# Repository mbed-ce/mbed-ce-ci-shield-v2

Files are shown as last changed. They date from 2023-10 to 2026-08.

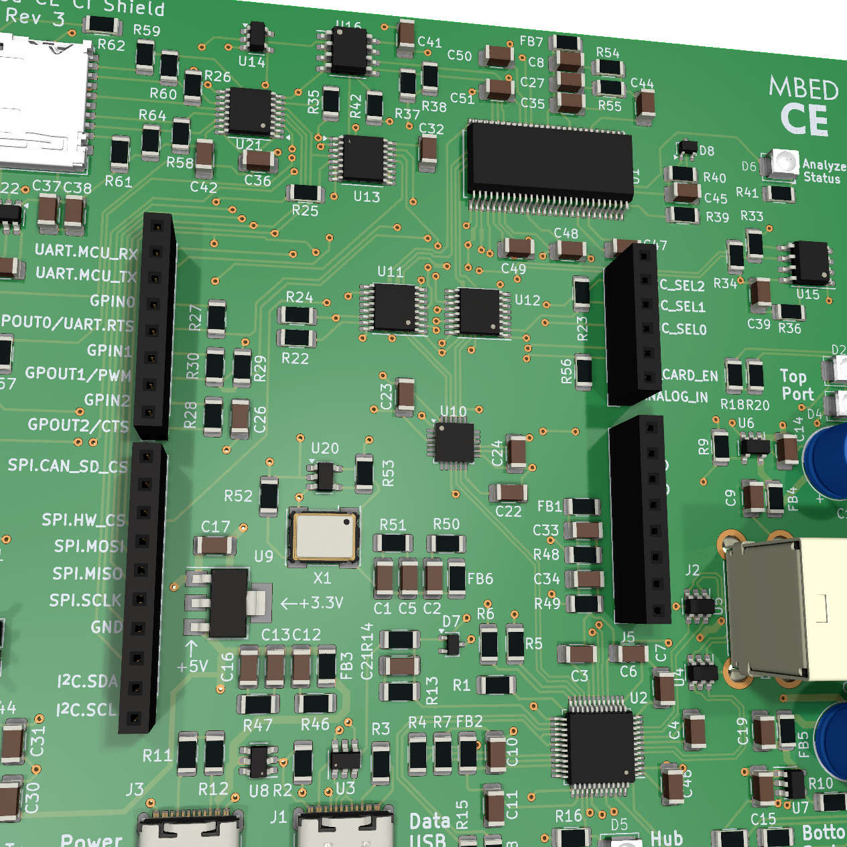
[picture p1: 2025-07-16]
Design Files/Rev3/img/render/mbed-ce-ci-shield-v2-top.png

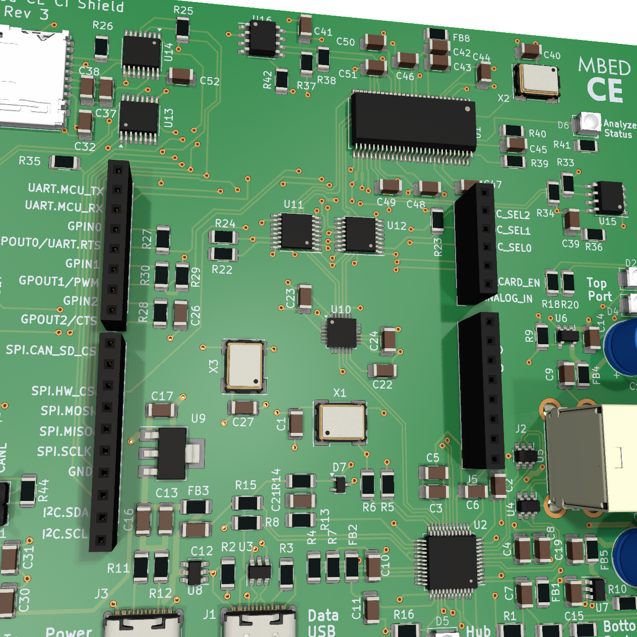
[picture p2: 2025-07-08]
Design Files/Rev3_rc1/img/render/mbed-ce-ci-shield-v2-top.png

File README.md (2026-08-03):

# Mbed CE CI Shield v2
CI Shield Board Photo
This repository contains version 2 of Mbed OS Community Edition's CI Test Shield board.  This PCB is designed to help test the low-level I/O functionality of many different MCUs supported by Mbed OS.

## High Level Functionality
This board contains the following hardware:
- 1x Infineon (Cypress) CY7C65632 4-Port USB 2.0 Hub
  - 2 ports are available externally, 2 ports are connected internally
- 1x Infineon (Cypress) CY7C65211 USB to SPI/I2C/UART adapter
  - This is connected to a number of different data lines via 4-to-1 multiplexer ICs.
- 1x Infineon (Cypress) FX2LP USB Microcontroller
  - This is programmed with Sigrok FX2LAFW firmware to turn it into an inexpensive plug-and-play logic analyzer
- 1x MicroSD card slot
- 1x 24FC64-I/SN 8KiB EEPROM
- 1x PWM to ADC loopback
- 1x Power USB Port (designed to be connected to a power source like a travel charger, data lines not hooked up)
- 1x Data USB Port (designed to be connected to a test runner machine, potentially a single board computer without too much power)

*Note: I swear I'm not sponsored by Infineon or anything, it just so happened that their chips were the best fit for everything I needed on the board.  I even tried to use an FT232H in the first rev of the hardware, but I could not for the life of me get it to work.*

It can test up to 10 different types of IO:
| IO Type | Test Method |
|---|---|
| **USB Device** | The Mbed target's USB Device port can be connected to one of the shield's downstream USB ports |
| **SPI Master** | The Mbed target can interact with the MicroSD card.  The logic analyzer can observe this interaction. |
| **SPI Slave** | The CY7C65211 can initiate SPI transactions which are handled by the MCU.  The logic analyzer can observe this interaction. |
| **I2C Master** | The Mbed target can talk to the EEPROM over I2C.  The logic analyzer can observe this interaction. |
| **I2C Slave** | The CY7C65211 can initiate I2C transactions which are handled by the MCU.  The logic analyzer can observe this interaction. |
| **UART** | The MCU can communicate with the CY7C65211 bidirectionally over UART.  The logic analyzer can observe this interaction. |
| **GPIO** (incl. interrupts) | The shield has 3 sets of "looped back" GPIOs, through which the MCU can send signals to itself.  The logic analyzer can observe this interaction. |
| **PWM** | The MCU outputs a PWM signal via GPIN1.  The logic analyzer measures the frequency and duty cycle. |
| **ADC** (AnalogIn) | The MCU outputs a PWM signal, which is averaged via an RC filter into a voltage.  This voltage is fed into the ADC and the test verifies whether it's read correctly. |
| **DAC** (AnalogOut) | The DAC outputs an analog signal which is fed into an ADC pin.  The test verifies whether the output matches the input. |

## Board Design Files

The complete schematic PDF can be seen here: https://github.com/mbed-ce/mbed-ce-ci-shield-v2/blob/master/Design%20Files/Rev2/docs/mbed-ce-ci-shield-v2-schematic.pdf

## The Logic Analyzer

### Input Mapping

Logic analyzer inputs are muxed by the FUNC_SEL[0..2] pins.

| Analyzer Input | FUNC_SEL = 000 | FUNC_SEL = 001 | FUNC_SEL = 010 | FUNC_SEL = 1xx |
|---|---|---|---|---|
| D0 | UART.MCU_TX | NC | SPI.HW_CS | NC |
| D1 | UART.RTS | I2C.SCL | SPI.MISO | NC |
| D2 | UART.CTS | I2C.SDA | SPI.MOSI | NC |
| D3 | UART.MCU_RX | NC | SPI.SCLK | NC |
| D4 | SPI.SD_CS | SPI.SD_CS | SPI.SD_CS | SPI.SD_CS |
| D5 | GPOUT0 | GPOUT0 | GPOUT0 | GPOUT0 |
| D6 | GPOUT1/PWM | GPOUT1/PWM | GPOUT1/PWM | GPOUT1/PWM |
| D7 | GPOUT2 | GPOUT2 | GPOUT2 | GPOUT2 | 

## Board Bringup and Testing
### Initial Testing
Before powering on a board, check that the resistance across the 5V rail is at least 10kOhms and the resistance across the 3V3 rail is at least 600 ohms.  These rails can be found on the LD1117S33 voltage regulator pins. For ground, use the outside of the double USB-A port (NOT the USB-C ports, their shields are not grounded). If these resistance checks fail, you almost certainly have a short somewhere.

When you first plug in a board, you should see three USB devices enumerate:
- One "Cypress Semiconductor Corp. Unprogrammed CY7C65632/34 hub HX2VL"
- One "Cypress Semiconductor Corp. USB-Serial (Single Channel)"
- One FX2LP in no-EEPROM mode (TODO what is this named in lsusb?)

If these USB devices do not enumerate, double-check the circuitry for the chips that don't enumerate.

Additionally, the current draw of the board should be between ~14mA and ~100mA when no Mbed board is connected.  A USB-C power meter (e.g. [this one](https://www.amazon.com/YOJOCK-Multimeter-Capacity-Voltmeter-Detector/dp/B0B99Z2GJK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)) is highly recommended when testing new boards.

### Flashing Logic Analyzer Firmware

To build and flash the logic analyzer firmware, you will need [Small Device C Compiler](https://sdcc.sourceforge.net/).  On Ubuntu, this can be installed with `sudo apt install sdcc sdcc-libraries`.  You will also need [the mbed-ce fork of fxload](https://github.com/mbed-ce/fxload).  Lastly, you will need access to a Linux command line environment -- WSL or MSYS2 should work if on Windows.

After installing these (and setting up udev rules for fxload, if on Linux), run the following commands from the repo root:

```
$ cd Firmware
$ python3 fx2lafw_update_serial_number.py 001 <replace 001 with the serial number you want to give this board>
$ cd sigrok-firmware-fx2lafw
$ ./autogen.sh
$ mkdir build
$ cd build
$ ../configure
$ make
$ fxload load_eeprom --ihex-path hw/sigrok-fx2-8ch/fx2lafw-sigrok-fx2-8ch.ihx -t FX2LP --control-byte 0xC2
```

Finally, unplug and replug the board from power and data.

Note: The python script run in step 2 works by modifying one of the fx2lafw source files to inject a unique serial number into the firmware, as I wasn't able to find any other way to do this.

### Flashing USB-Serial Adapter Configuration

To configure the USB-serial adapter (the CY7C65211), you will need to use Mbed CE's [cy_serial_bridge](https://github.com/mbed-ce/cy_serial_bridge) library.  This can be installed using `python3 -m pip install cy_serial_bridge`.  Then, we can use the following commands to load a configuration and program the serial number.

Note: If you have any other CI shields connected to the computer, you must unplug them before running these commands.

```
$ cy_serial_cli --pid 0x00fb load Firmware/CY7C65211-Configs/mbed_ce_cy7c65211a_cdc_base_config.bin
$ cy_serial_cli reconfigure --set-serno ShieldSN001 <replace 001 with the serial number you want to give this board>
$ cy_serial_cli change-type I2C # Change to I2C initially so it will not drive any lines on the board
```

## Using the Logic Analyzer
The logic analyzer integrated into this board runs firmware from the Sigrok project, and is designed to be used with the sigrok CLI and the PulseView GUI.  This provides a complete set of open-source tools for capturing and decoding traffic moving across the board.

### Side Note: Sigrok Windows Issues
There is currently no Sigrok/Pulseview release that is compatible with Windows 10 and fx2lafw; neither the nightlies nor the official releases.  I have contributed a [patch](https://github.com/sigrokproject/libsigrok/pull/242) that allows it to work, but to use it, you must install MSYS2 and compile libsigrok, libsigrok-decode, and pulseview from source.

### Using the Logic Analyzer via WSL2 on Windows
If you have Windows 11 and WSL2, you can proxy USB devices to WSL using `usbipd`.  I found that this worked perfectly fine for the FX2 logic analyzer on the board.  First install usbipd using [these instructions](https://github.com/dorssel/usbipd-win/wiki/WSL-support).  Then, follow the linux instructions which follow.

### Using the Logic Analyzer on Linux
First, you need to install the udev rules. Copy the 60-libsigrok.rules and 61-libsigrok-plugdev.rules files from [here](https://github.com/sigrokproject/libsigrok/blob/master/contrib/) into /etc/udev/rules.d.  Then, make sure your user account is in the `plugdev` group.  Finally, run:
```
$ sudo udevadm control --reload-rules
$ sudo udevadm trigger
```

If on WSL2 and the first command gives an error, run
```
$ sudo service udev restart
```
first.

You should now be able to run sigrok without root.  Now, you can run:
```
$ sigrok-cli -d fx2lafw --scan
```
and you should see something like
```
The following devices were found:
fx2lafw:conn=1.4 - sigrok FX2 LA (8ch) with 8 channels: D0 D1 D2 D3 D4 D5 D6 D7
```
This means your logic analyzer is working!

## Building the Design with KiBot

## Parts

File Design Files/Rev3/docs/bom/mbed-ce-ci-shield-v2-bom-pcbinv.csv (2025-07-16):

References | Description | Part | Value | Supplier | SKU | Footprint | LibRef | Qty
C1 C3 C4 C6 C7 C10 C11 C16 C23 C24 C32 C35 C38 C39 C41 C44 C45 C46 C47 C48 C49 C50 C51 | Unpolarized capacitor, small symbol | C_Small | 100nF | Digi-Key |  | C_1206_3216Metric | GRM319R72A104KA01D | 23
C14 C15 C22 C25 C26 C28 C29 C30 C31 C36 C40 C42 | Unpolarized capacitor, small symbol | C_Small | 1u | Digi-Key |  | C_1206_3216Metric | CL31B105KBHNNNE | 12
C2 C5 C8 C9 C12 C13 C19 C21 C27 C33 C34 | Unpolarized capacitor, small symbol | C_Small | 2.2uF | Digi-Key | 1276-1291-1-ND | C_1206_3216Metric | CL31B225KBHNNNE | 11
C17 C37 C43 | Unpolarized capacitor, small symbol | C_Small | 10u | Digi-Key |  | C_1206_3216Metric | CL31B106KLHNNNE | 3
C18 C20 | Polarized capacitor, US symbol | C_Polarized_US | 100u | Digi-Key | 493-6630-1-ND | CP_Radial_D8.0mm_P3.50mm | RL81V101MDN1KX | 2
D1 D2 | Green LED 100mcd 20mA Vf=2.1V | AA3528CGSK | AA3528CGSK | Digi-Key | 754-1528-1-ND | AA3528 |  | 2
D5 D6 | Red LED 100mcd 20mA Vf=1.95V | AA3528SURSK | AA3528SURSK | Digi-Key | 754-1537-1-ND | AA3528 |  | 2
D3 D4 | Yellow LED 200mcd 20mA Vf=2V | AA3528SYSK | AA3528SYSK | Digi-Key | 754-1539-1-ND | AA3528 |  | 2
D7 D8 | Schottky barrier diode, SOT-323 | BAT54W | BAT54W | Digi-Key | 4878-BAT54WCT-ND | SOT-323_SC-70 |  | 2
FB1 FB2 FB3 FB4 FB5 FB6 FB7 | Ferrite bead, small symbol | FerriteBead_Small | 300@100MHz | Digi-Key | 732-4654-1-ND | R_1206_3216Metric | 742792121 | 7
J7 | Generic connector, single row, 01x10, script generated (kicad-library-utils/schlib/autogen/connector/) | Conn_01x10 | 1x10 | Digi-Key | SSW-110-03-T-S-ND | PinSocket_1x10_P2.54mm_Vertical | HEADER_10x1_LONG_TAIL | 1
J9 J10 J11 | Generic connector, single row, 01x02, script generated | Conn_01x02_Pin | 1x2 | Digi-Key | 732-5315-ND | PinHeader_1x02_P2.54mm_Vertical | HEADER_2x1 | 3
J6 | Generic connector, single row, 01x06, script generated (kicad-library-utils/schlib/autogen/connector/) | Conn_01x06 | 1x6 | Digi-Key | SAM8865-ND | PinSocket_1x06_P2.54mm_Vertical | HEADER_6x1_LONG_TAIL | 1
J4 J5 | Generic connector, single row, 01x08, script generated (kicad-library-utils/schlib/autogen/connector/) | Conn_01x08 | 1x8 | Digi-Key | SAM8866-ND | PinSocket_1x08_P2.54mm_Vertical | HEADER_8x1_LONG_TAIL | 2
J8 | Micro SD Card Socket with card detection pins | Micro_SD_Card_Det_Hirose_DM3AT | DM3AT | Digi-Key | HR1964CT-ND | microSD_HC_Hirose_DM3AT-SF-PEJM5 |  | 1
J2 | USB Type A connector, stacked | USB_A_Stacked | UJ2-ADH-3-TH | Digi-Key | 102-5876-ND | USB_A_CUI_UJ2-ADH-TH_Horizontal_Stacked |  | 1
J1 J3 | USB 2.0-only 16P Type-C Receptacle connector | USB_C_Receptacle_USB2.0_16P | USB4105-GF-A | Digi-Key | 2073-USB4105-GF-ACT-ND | USB_C_Receptacle_GCT_USB4105-xx-A_16P_TopMnt_Horizontal-ExtraHoleClearance |  | 2
M1 M2 | 0.1" Jumper / Shunt | Jumper | QPC02SXGN-RC | Digi-Key | S9337-ND |  |  | 2
R46 R47 R48 R49 R50 R51 R54 R55 | Resistor, US symbol | R_US | 1 | Digi-Key | P1.0RCT-ND | R_1206_3216Metric | ERJ-8RQF1R0V | 8
R52 R53 | Resistor, US symbol | R_US | 33 | Digi-Key | 541-CRCW120633R0FKEACCT-ND | R_1206_3216Metric | CRCW120633R0FKEAC | 2
R32 R44 | Resistor, US symbol | R_US | 120 | Digi-Key | P120FCT-ND | R_1206_3216Metric | ERJ-8ENF1200V | 2
R17 R18 | Resistor, US symbol | R_US | 270 | Digi-Key | P270FCT-ND | R_1206_3216Metric | ERJ-8ENF2700V | 2
R19 R20 R21 | Resistor, US symbol | R_US | 300 | Digi-Key | P300FCT-ND | R_1206_3216Metric | P300FCT-ND | 3
R1 | Resistor, US symbol | R_US | 649 | Digi-Key | 311-649FRCT-ND | R_1206_3216Metric | RC1206FR-07649RL | 1
R41 | Resistor, US symbol | R_US | 820 | Digi-Key | 311-820FRCT-ND | R_1206_3216Metric | RC1206FR-07820RL | 1
R27 R28 R30 R62 | Resistor, US symbol | R_US | 1k | Digi-Key | P1.00KFCT-ND | R_1206_3216Metric | ERJ-8ENF1001V | 4
R33 R34 | Resistor, US symbol | R_US | 1.1k | Digi-Key | 311-1.10KFRCT-ND | R_1206_3216Metric | RC1206FR-071K1L | 2
R29 | Resistor, US symbol | R_US | 1.5k | Digi-Key | 311-1.50KFRCT-ND | R_1206_3216Metric | RC1206FR-071K5L | 1
R37 R38 | Resistor, US symbol | R_US | 2.2k | Digi-Key | 311-2.20KFRCT-ND | R_1206_3216Metric | RC1206FR-072K2L | 2
R14 R25 | Resistor, US symbol | R_US | 4.7k | Digi-Key | P4.70KFCT-ND | R_1206_3216Metric | ERJ-8ENF4701V | 2
R2 R3 R11 R12 | Resistor, US symbol | R_US | 5.1k | Digi-Key | 311-5.10KFRCT-ND | R_1206_3216Metric | RC1206FR-075K1L | 4
R13 | Resistor, US symbol | R_US | 9.1k | Digi-Key | P9.10KFCT-ND | R_1206_3216Metric | ERJ-8ENF9101V | 1
R15 R22 R23 R24 R26 R31 R35 R36 R39 R42 R43 R45 R56 R57 R58 R59 R60 R61 R63 R64 | Resistor, US symbol | R_US | 10k | Digi-Key | P10.0KFCT-ND | R_1206_3216Metric | ERJ-8ENF1002V | 20
R4 R5 R6 R7 R8 R9 R10 R16 R40 | Resistor, US symbol | R_US | 100k | Digi-Key | P100KFCT-ND | R_1206_3216Metric | ERJ-8ENF1003V | 9
U15 U16 | I2C Serial EEPROM, 2Kb, DIP-8/SOIC-8/TSSOP-8/DFN-8 | 24LC02 | 24FC64-I/SN | Digi-Key | 24FC64T-I/SNCT-ND | SOIC-8_3.9x4.9mm_P1.27mm |  | 2
U14 | Single NOT Gate, Low-Voltage CMOS | 74AHC1G04 | 74AHC1G04 | Digi-Key | 296-1089-1-ND | SOT-23-5 | SN74AHC1G04DBVR | 1
U20 | Single D Flip-Flop, Inverted Output, Low-Voltage CMOS | 74LVC1G80 | 74LVC1G80 | Digi-Key | 296-9851-1-ND | SOT-23-5 | SN74LVC1G80DBVR | 1
U13 | Triple SPDT CMOS Analog Switch, 2.5Ohm Ron, TSSOP-16 | ADG733BRU | ADG733BRU | Digi-Key | ADG733BRUZ-REEL7CT-ND | TSSOP-16_4.4x5mm_P0.65mm |  | 1
U22 | Load Switch w/ Discharge Resistor | AP22913W6-7 | AP22913W6-7 | Digi-Key | AP22913W6-7DICT-ND | SOT-23-6 |  | 1
U6 U7 | Current Limit IC 0.5-1.0A, SOT-23-5 | BD2221G-LBTR | BD2221G-LBTR | Digi-Key | BD2221G-LBTRCT-ND | SOT-23-5 |  | 2
U10 | Full Speed USB to Serial (UART/SPI/I2C) Bridge, 3MHz Max Speed, With GPIOs, 24-QFN | CY7C65211A | CY7C65211A | Digi-Key | 448-CY7C65211A-24LTXI-ND | QFN-24-1EP_4x4mm_P0.5mm_EP2.65x2.65mm-LengthenedPads |  | 1
U2 | 4 Port USB Hub Controller USB 2.0 48-TQFP | CY7C65632-48AXCT | CY7C65632-48AXCT | Digi-Key | 448-CY7C65632-48AXCT-ND | LQFP-48_7x7mm_P0.5mm |  | 1
U1 | CYPRESS FX2LP USB Microcontroller, 48MHz 8051, 16KB RAM, USB 2.0, I2C, SSOP-56 | CY7C68013A-56PVX | CY7C68013A-56PVX | Digi-Key | 448-CY7C68013A-56PVXCT-ND | SSOP-56_7.5x18.5mm_P0.635mm |  | 1
U9 | 800mA Fixed Low Drop Positive Voltage Regulator, Fixed Output 3.3V, SOT-223 | LD1117S33TR_SOT223 | LD1117S33TR | Digi-Key | 497-1242-1-ND | SOT-223-3_TabPin2 |  | 1
U17 | Stand-Alone CAN Controller with SPI Interface, TSSOP-20 | MCP2515-xST | MCP2515-xST | Digi-Key | MCP2515T-I/STCT-ND | TSSOP-20_4.4x6.5mm_P0.65mm |  | 1
U21 | 4 Channel Bidirectional Level Shifter with Selectable Direction, TSSOP-16 | SN74AXC4T774 | SN74AXC4T774 | Digi-Key | 296-SN74AXC4T774PWRCT-ND | TSSOP-16_4.4x5mm_P0.65mm |  | 1
U11 U12 | CMOS DPQT analog multiplexer/demultiplexer, TSSOP-16 | SN74CB3Q3253PWR | SN74CB3Q3253PWR | Digi-Key | 296-19135-1-ND | TSSOP-16_4.4x5mm_P0.65mm |  | 2
U18 U19 | High-Speed CAN Transceiver, separate VIO, silent mode, SOIC-8 | TJA1051T-3 | TJA1051T-3 | Digi-Key | 568-8684-1-ND | SOIC-8_3.9x4.9mm_P1.27mm |  | 2
U3 U4 U5 U8 | Very low capacitance ESD protection diode, 2 data-line, SOT-23-6 | USBLC6-2SC6 | USBLC6-2SC6 | Digi-Key | 497-5235-1-ND | SOT-23-6 |  | 4
X1 | 3.3V HCMOS SMD Crystal Clock Oscillator, Abracon | ASV-xxxMHz | 24.000MHz | Digi-Key | 535-9317-1-ND | Oscillator_SMD_Abracon_ASV-4Pin_7.0x5.1mm | ASV-24.000MHZ-EJ-T | 1

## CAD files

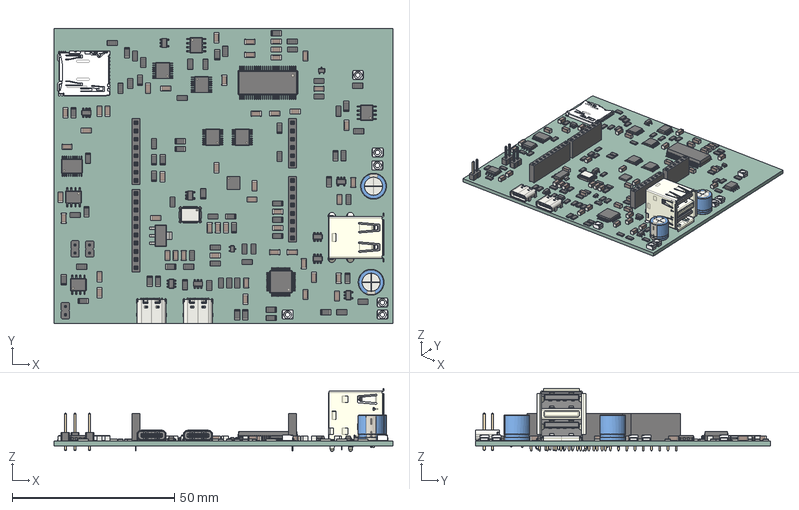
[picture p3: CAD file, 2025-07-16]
Design Files/Rev3/cad/mbed-ce-ci-shield-v2.step
104.5 x 91.0 x 19.4 mm
C_1206_3216Metric x 49
SSOP-56_7.5x18.5mm_P0.635mm
R_1206_3216Metric x 71
TSSOP-16_4.4x5mm_P0.65mm x 4
PinSocket_1x08_P2.54mm_Vertical x 2
CP_Radial_D80mm_P350mm x 2
SOT-23-6 x 5
SOIC-8_3.9x4.9mm_P1.27mm x 4
PinSocket_1x10_P2.54mm_Vertical
SOT-323_SC-70 x 2
USB_C_Receptacle_16P_TopMnt_Horizontal_GCT_USB4105-xx-A x 2
SOT-23-5 x 4
Oscillator_SMD_Abracon_ASV-4Pin_7.0x5.1mm
LQFP-48_7x7mm_P0.5mm
PinSocket_1x06_P2.54mm_Vertical
PinHeader_1x02_P254mm_Vertical x 3
QFN-24-1EP_4x4mm_Pitch0.5mm
DM3AT-SF-PEJM5
TSSOP-20_4.4x6.5mm_P0.65mm
SOT-223
CUI_DEVICES_UJ2-ADH-3-TH
kibot_rdlwfuhl_PCB

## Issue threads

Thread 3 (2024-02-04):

Build and debug first Rev 2 board

multiplemonomials, 2024-02-04:

multiplemonomials, 2024-04-30:
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

multiplemonomials, 2024-05-05:
Notes on things to fix in the PCB:
- Voltage divider which produces reset for CY7C65211 is sized incorrectly, not producing 3.3V.
- SD card is producing some valid data but is not actually coming up.  Need to debug.
- Should add zener diode to make sure that CY7C65211 reset is not high when VDD is 0V, so that the data usb only being plugged in doesn't break stuff.  Also is it a risk of triggering the ESD diode?
- SPI loopback resistor appears to be too high value.  Can't reliably do SPI loopback at 1MHz on LPC1768.  Need to look with a scope, and maybe switch out for like a 2.2k

multiplemonomials, 2024-07-07:
- SD card driver requires a pullup on MISO for correct operation.
- Should set it so that the SPI loopback is only active when the SD card is powered off

multiplemonomials, 2024-08-04:
- On the Arduino Uno R4, pin A0 is the DAC pin.  May wish to move the pinmappings around so that pin A0 is free for DAC purposes.

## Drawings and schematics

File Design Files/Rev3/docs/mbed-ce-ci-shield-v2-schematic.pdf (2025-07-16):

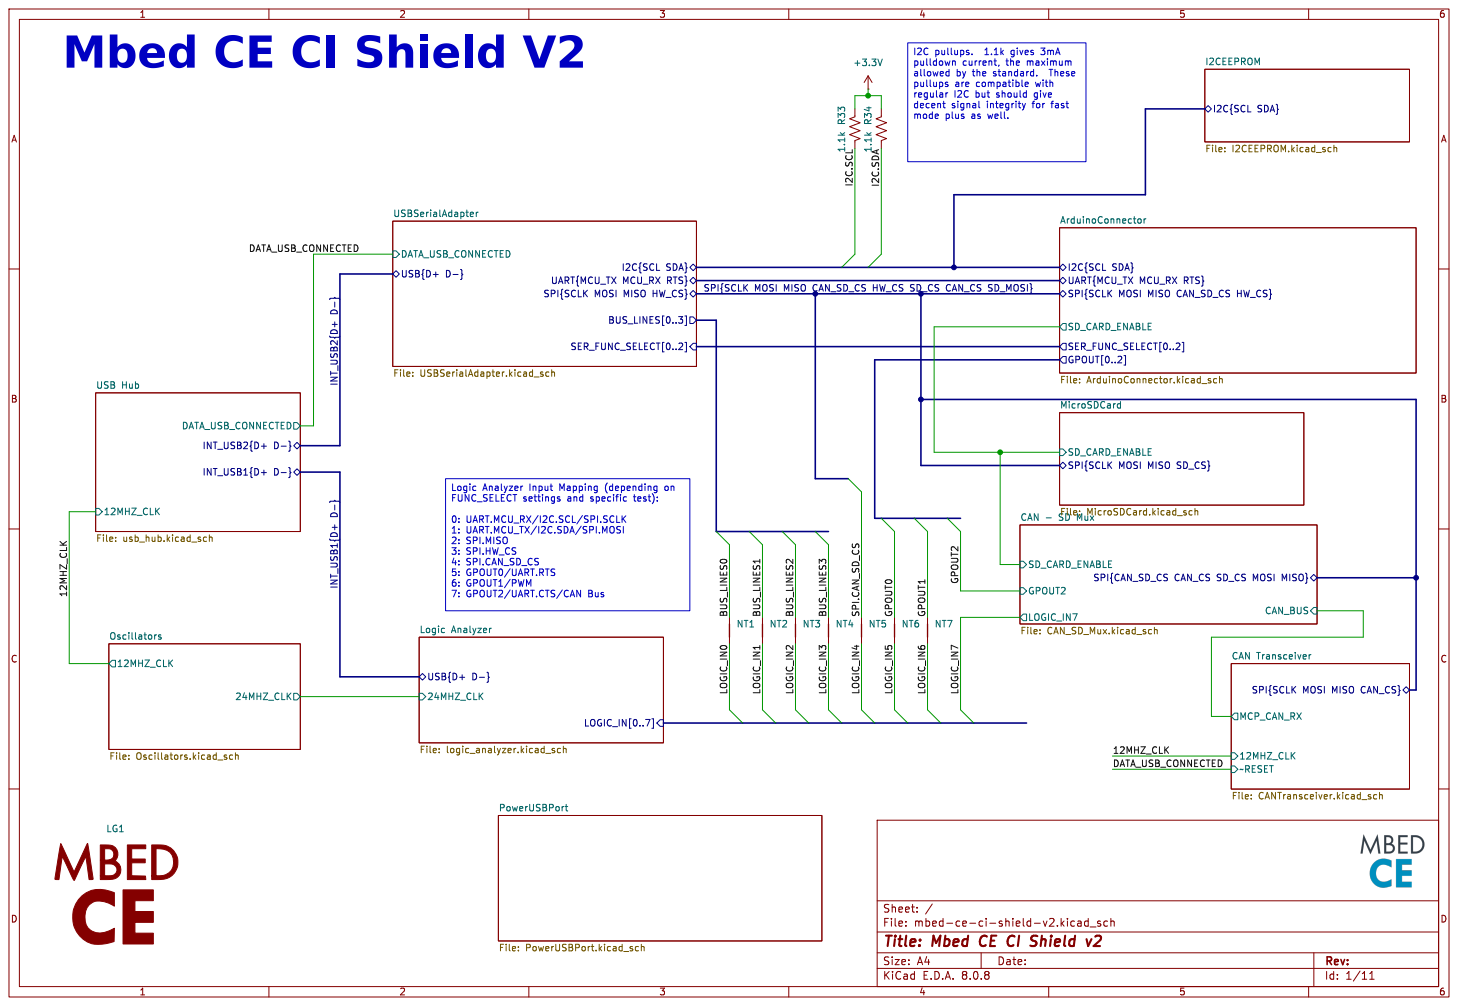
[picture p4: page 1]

USBSerialAdapter File: USBSerialAdapter.kicad_sch PowerUSBPort File: PowerUSBPort.kicad_sch

regular I2C but should give

UART{MCU_TX MCU_RX RTS}
SPI{SCLK MOSI MISO HW_CS}

SPI{SCLK MOSI MISO CAN_SD_CS HW_CS SD_CS CAN_CS SD_MOSI} LOGIC_IN4

SPI{SCLK MOSI MISO CAN_SD_CS HW_CS}

1: UART.MCU_TX/I2C.SDA/SPI.MOSI 2: SPI.MISO

12MHZ_CLK CAN Transceiver File: CANTransceiver.kicad_sch

File: mbed-ce-ci-shield-v2.kicad_sch Sheet: / 12MHZ_CLK

Id: 1/11 Title: Mbed CE CI Shield v2

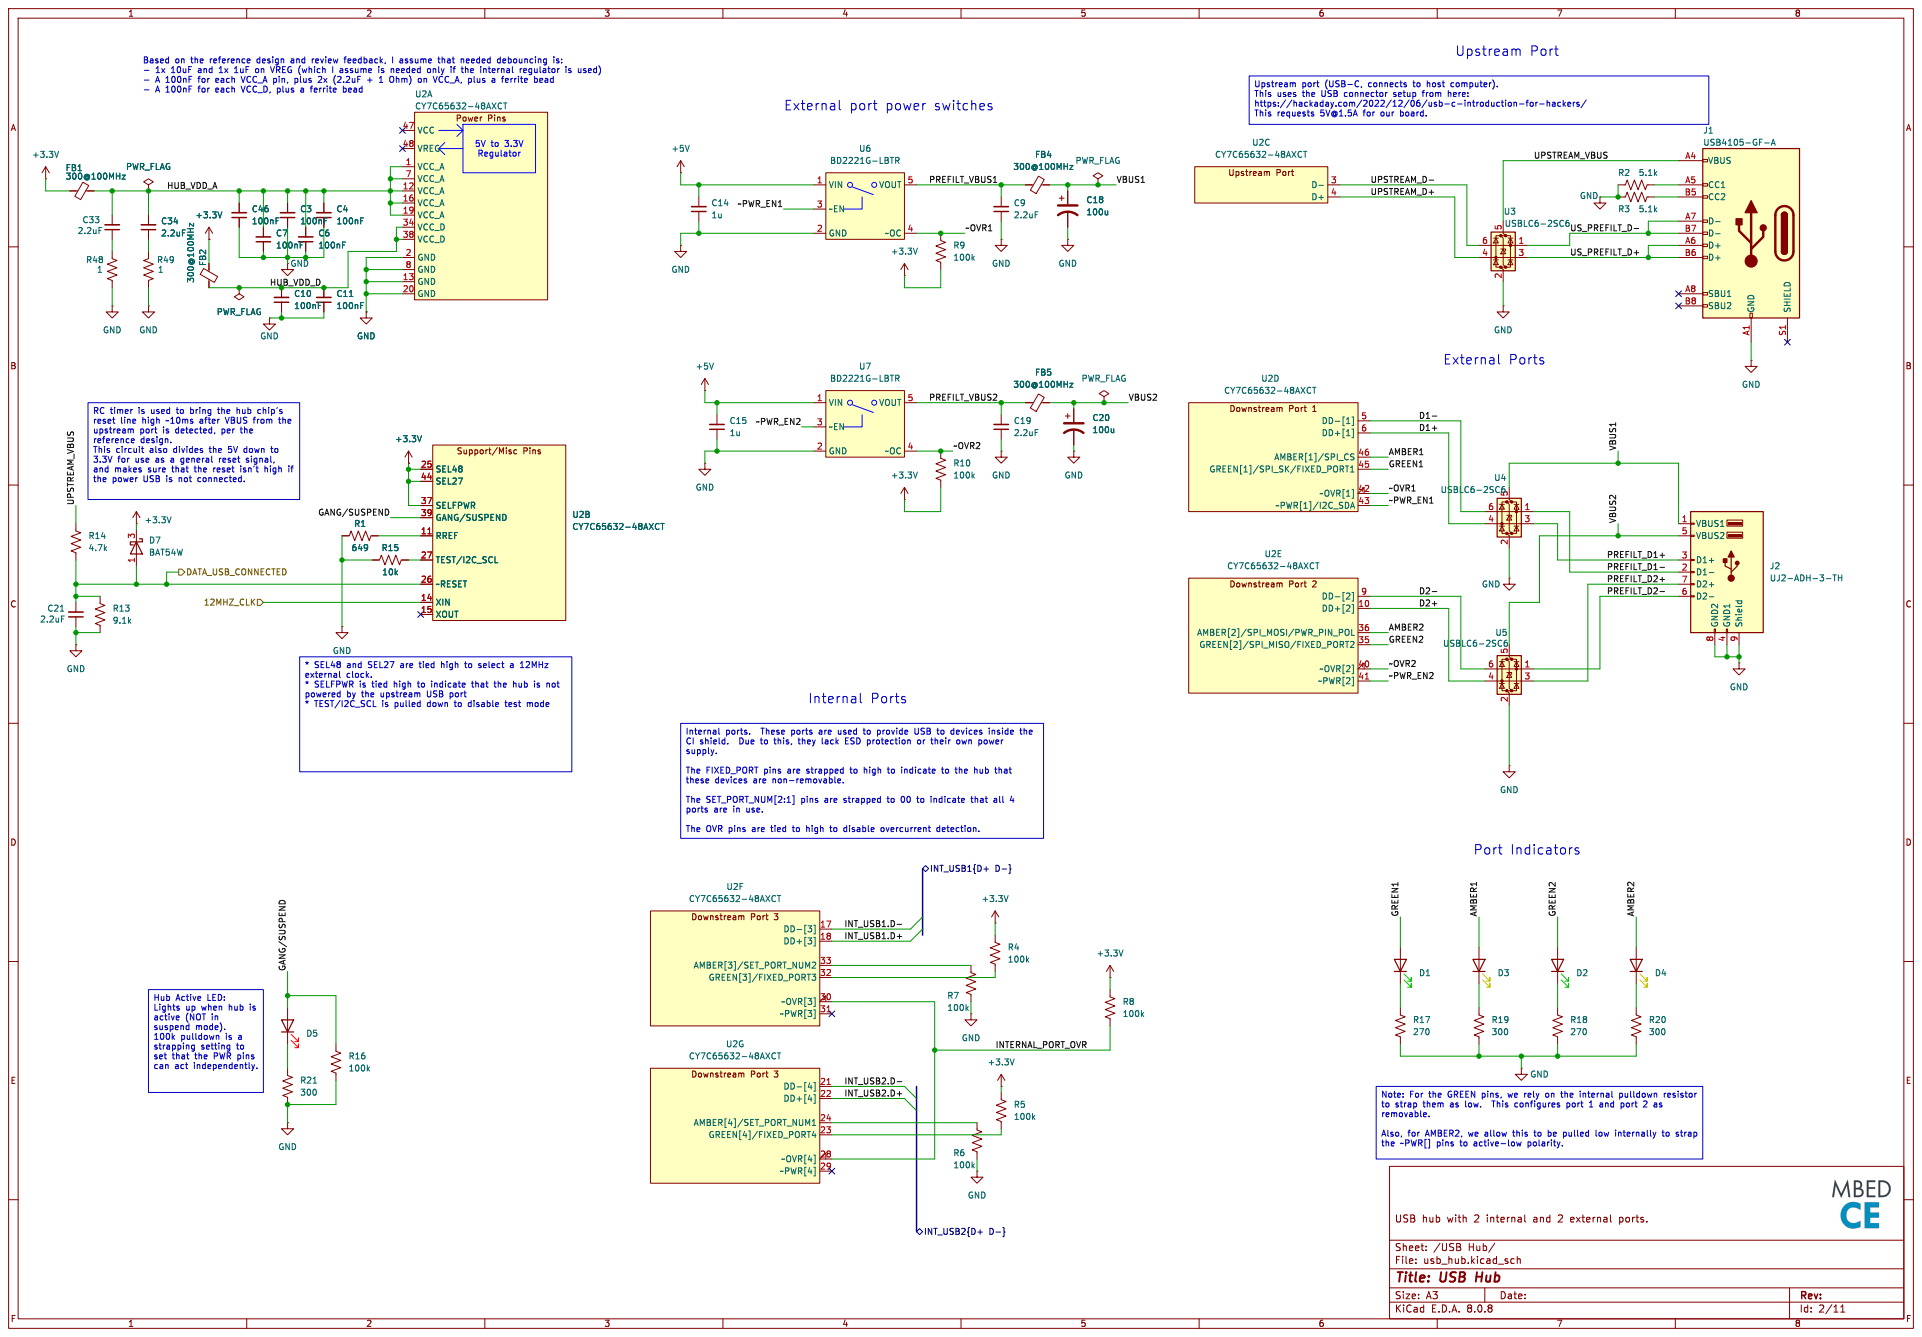
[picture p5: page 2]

- A 100nF for each VCC_A pin, plus 2x (2.2uF + 1 Ohm) on VCC_A, plus a ferrite bead

Regulator Power Pins VCC_A 1 VCC_A 12 GND 13 VCC_A 16 VCC_A 19 GND 2 GND 20 VCC_D 34 VCC_D 38 VCC 47 VREG 48 VCC_A 7 GND 8 U2A CY7C65632-48AXCT

External port power switches

reset line high ~10ms after VBUS from the
3.3V for use as a general reset signal, and makes sure that the reset isn't high if

Hub Active LED: Lights up when hub is active (NOT in

set that the PWR pins

Id: 2/11 Title: USB Hub

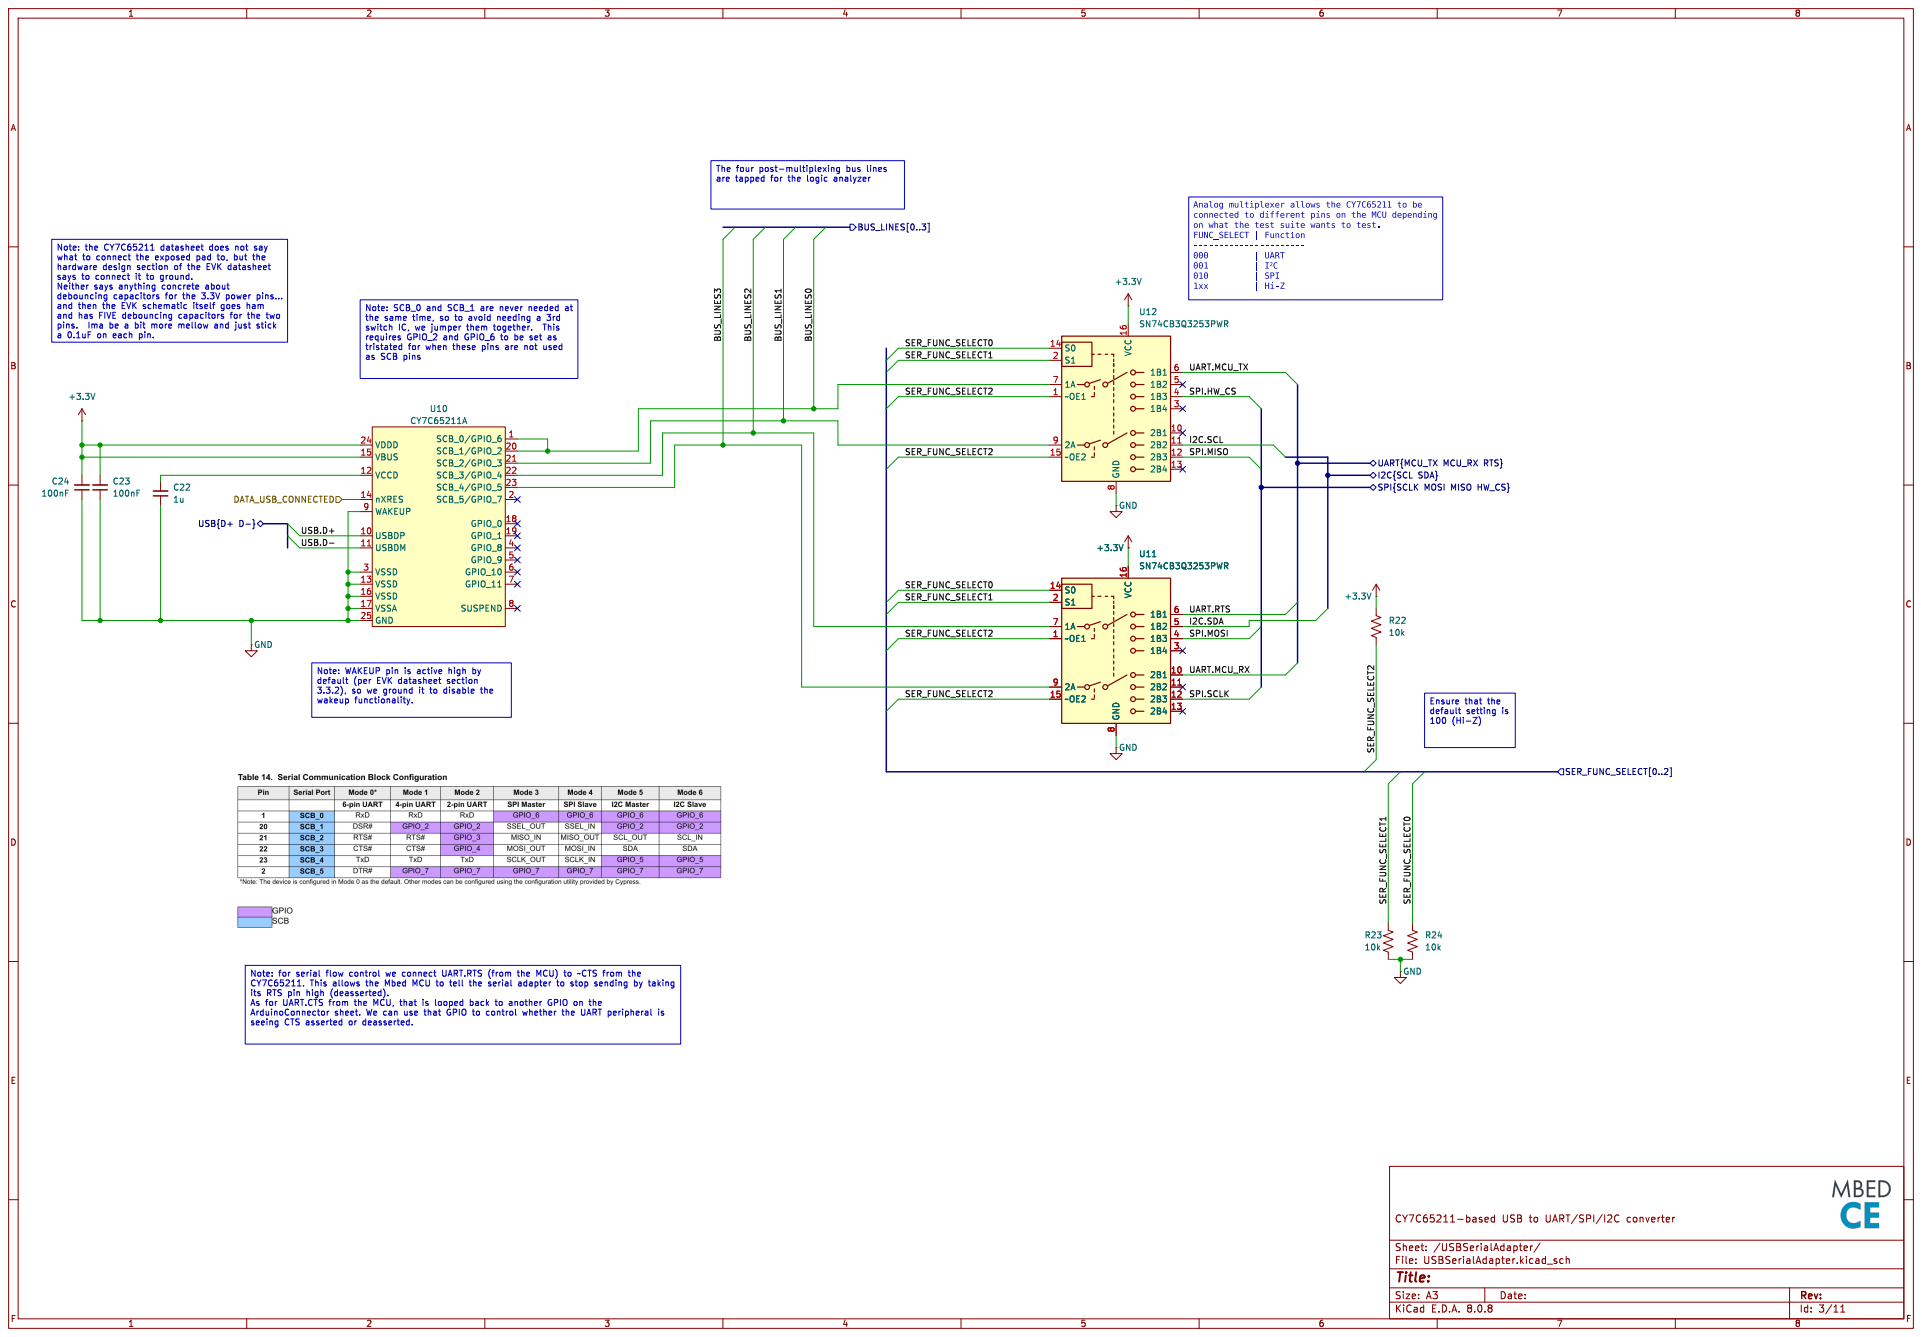
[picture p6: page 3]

3.3.2), so we ground it to disable the wakeup functionality. Note: SCB_0 and SCB_1 are never needed at

the same time, so to avoid needing a 3rd
requires GPIO_2 and GPIO_6 to be set as

UART{MCU_TX MCU_RX RTS}
I2C{SCL SDA}
SPI{SCLK MOSI MISO HW_CS}

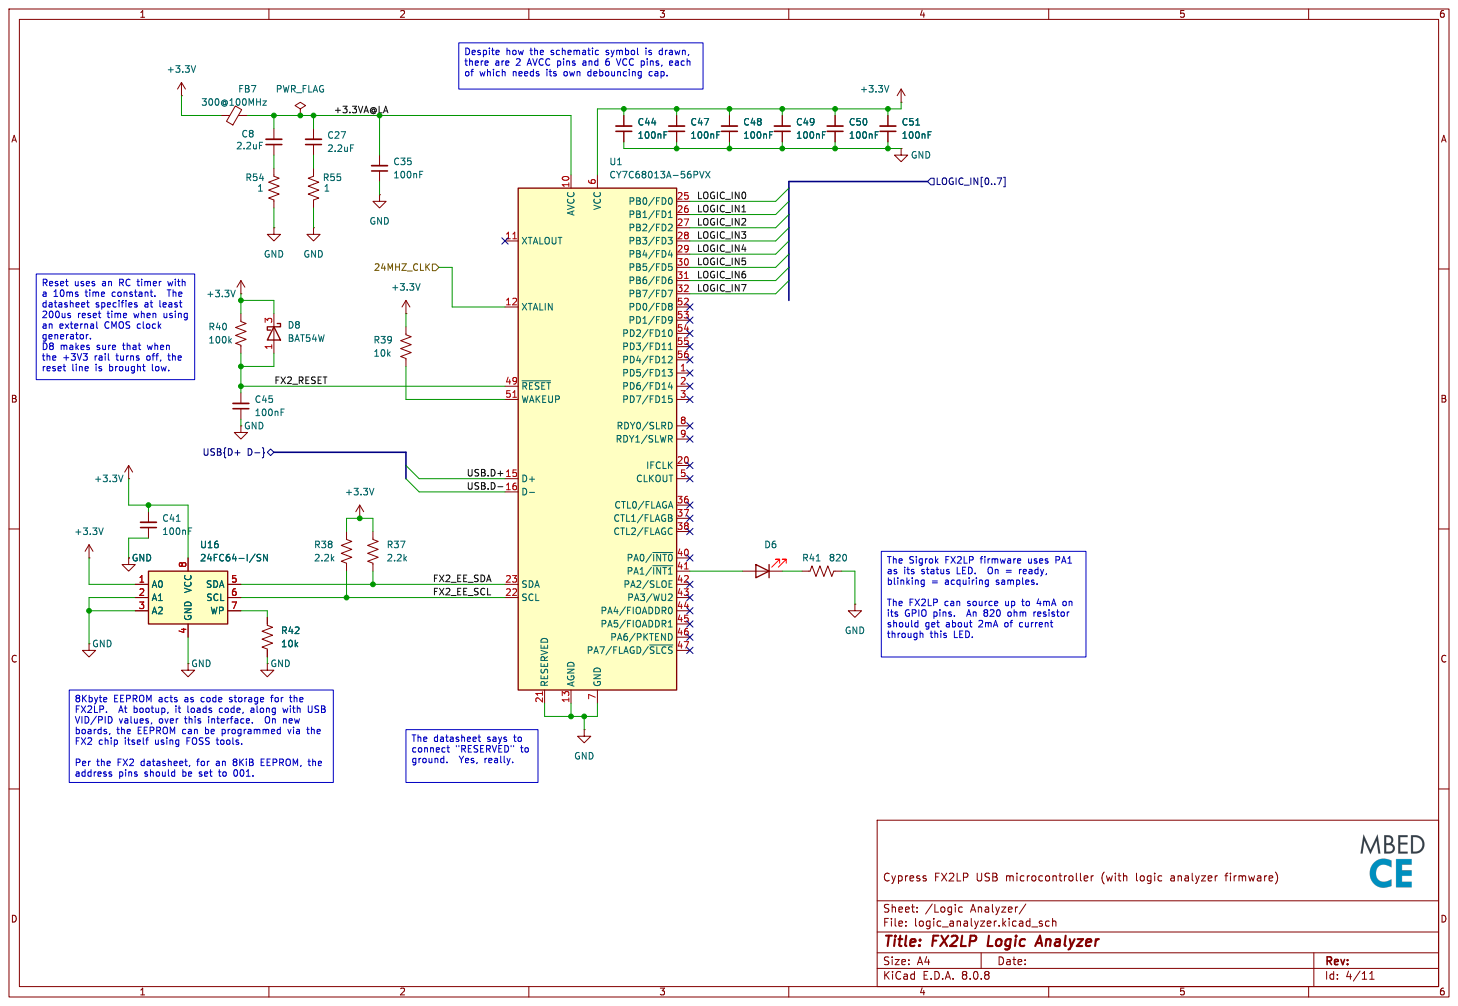
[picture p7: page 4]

there are 2 AVCC pins and 6 VCC pins, each
300@100MHz GND

the +3V3 rail turns off, the

4 SDA 5 SCL 6 WP 7 VCC

as its status LED. On = ready,

address pins should be set to 001.

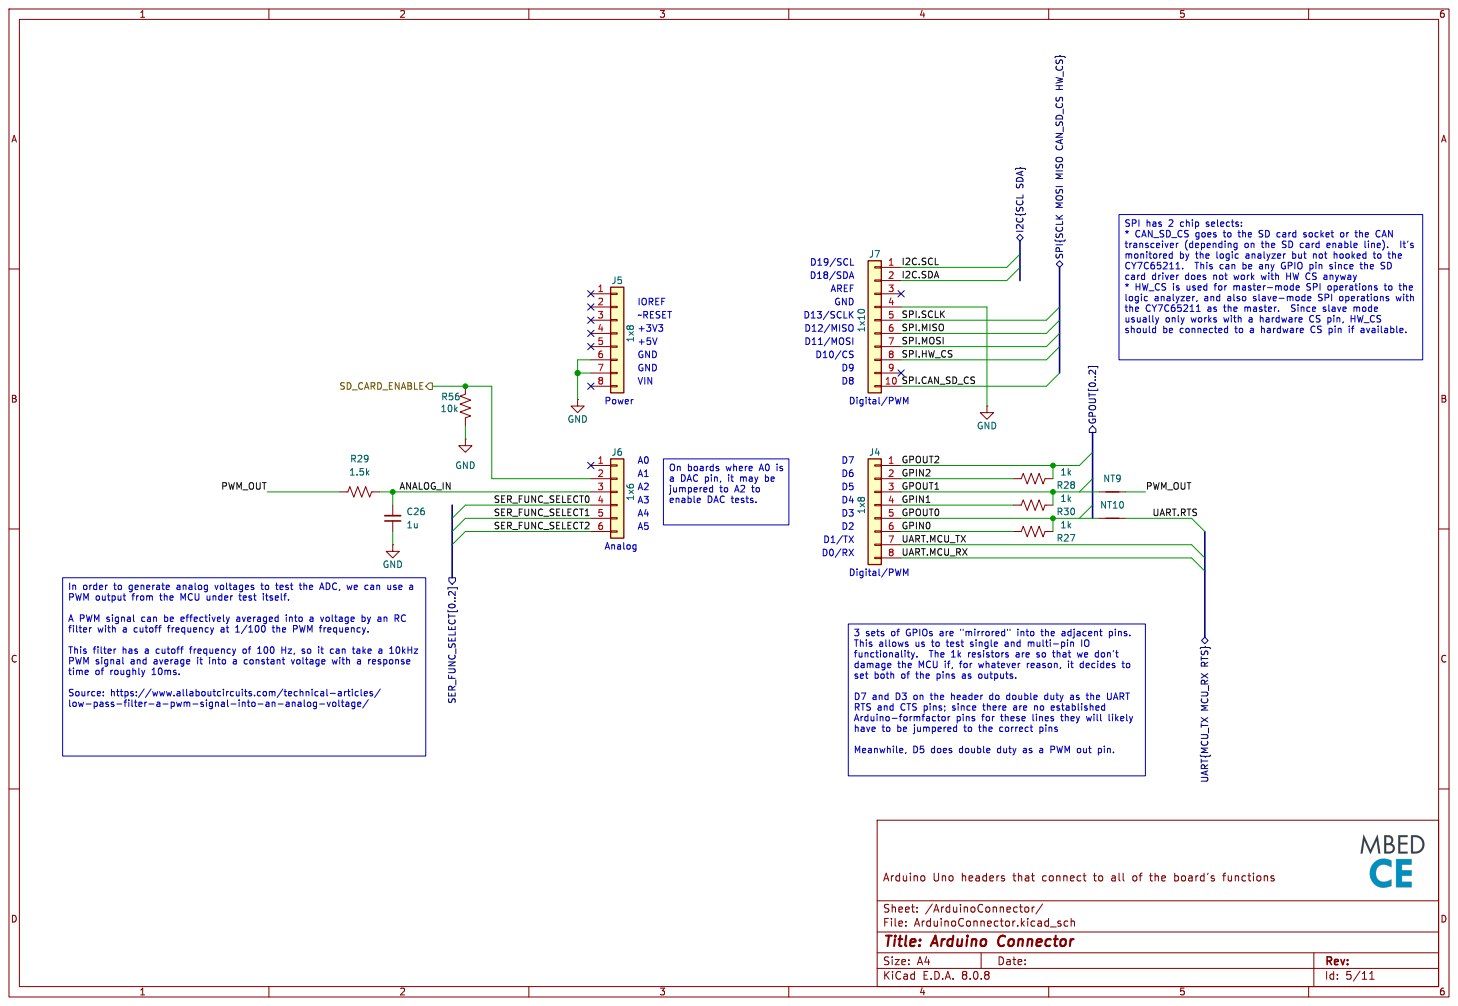
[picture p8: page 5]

card driver does not work with HW CS anyway
usually only works with a hardware CS pin, HW_CS

time of roughly 10ms. Source: https://www.allaboutcircuits.com/technical-articles/

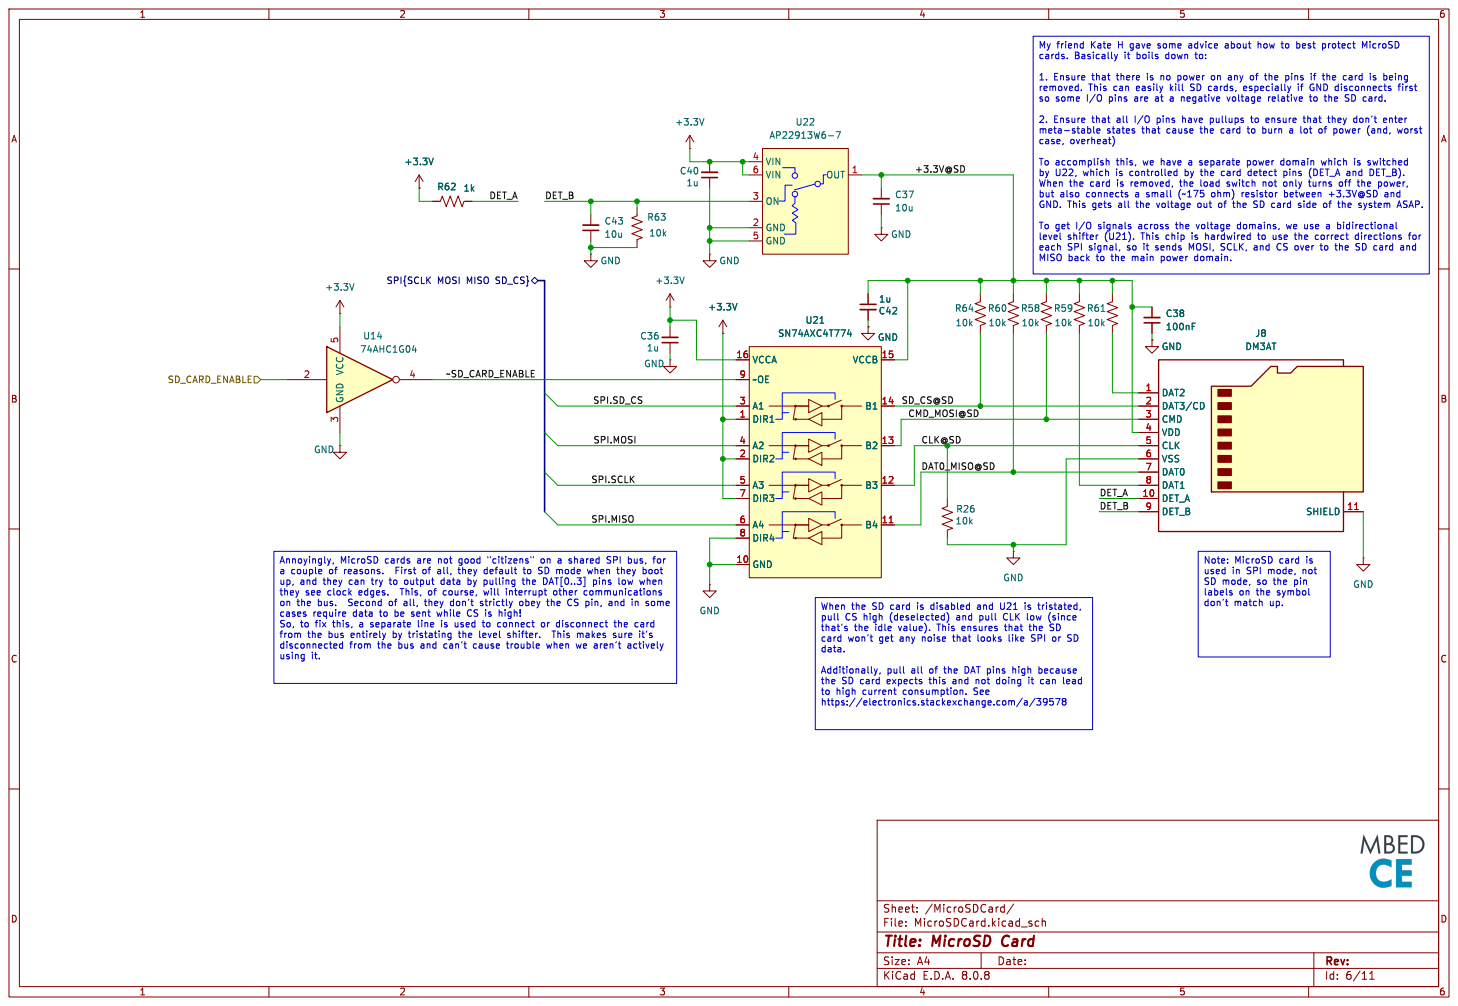
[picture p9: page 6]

My friend Kate H gave some advice about how to best protect MicroSD

SPI.SD_CS
SPI.MOSI SPI.MISO

labels on the symbol don't match up.

that's the idle value). This ensures that the SD
card won't get any noise that looks like SPI or SD

the SD card expects this and not doing it can lead
https://electronics.stackexchange.com/a/39578

File: MicroSDCard.kicad_sch Sheet: /MicroSDCard/
Id: 6/11 Title: MicroSD Card

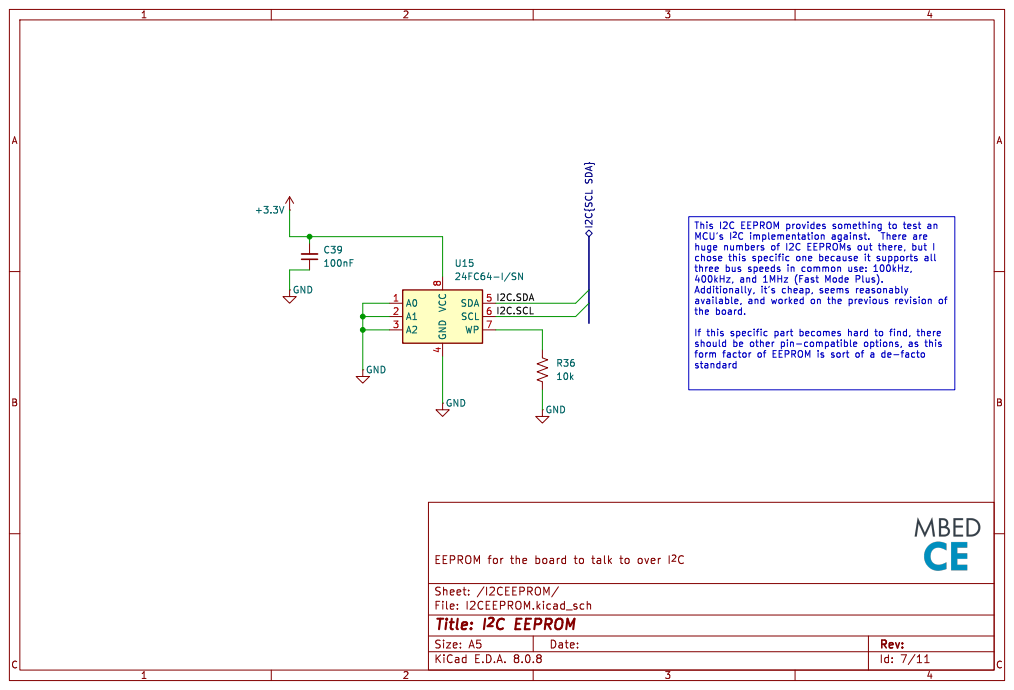
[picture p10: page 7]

4 SDA 5 SCL 6 WP 7 VCC

form factor of EEPROM is sort of a de-facto
standard

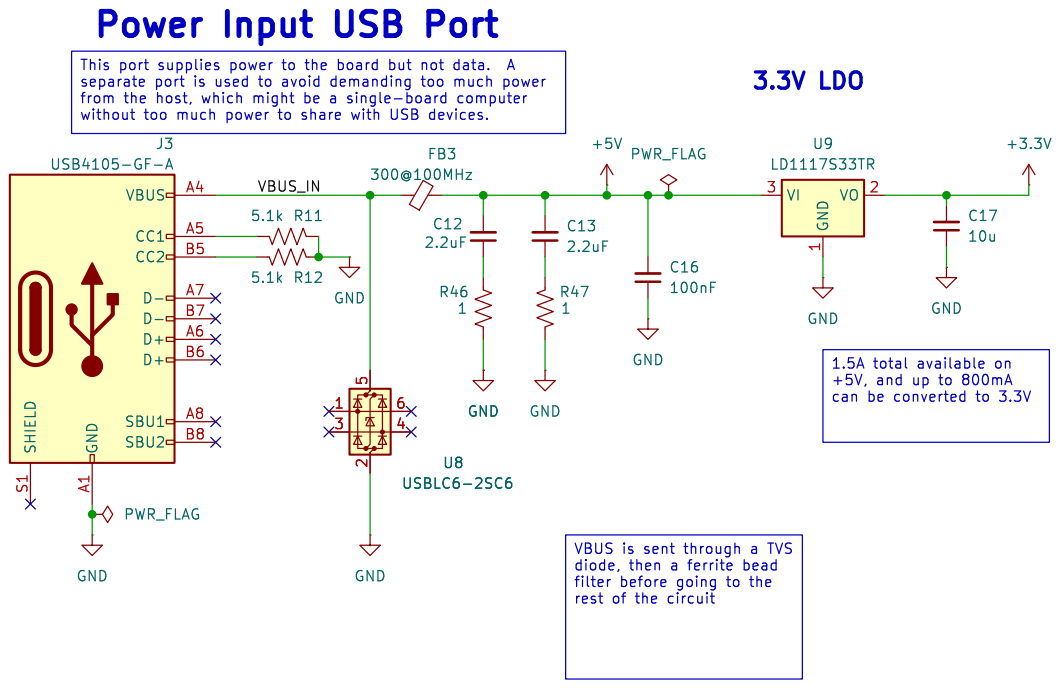
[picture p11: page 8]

VBUS is sent through a TVS
diode, then a ferrite bead
filter before going to the

Id: 8/11 Title: Power Input USB Port File: PowerUSBPort.kicad_sch Sheet: /PowerUSBPort/

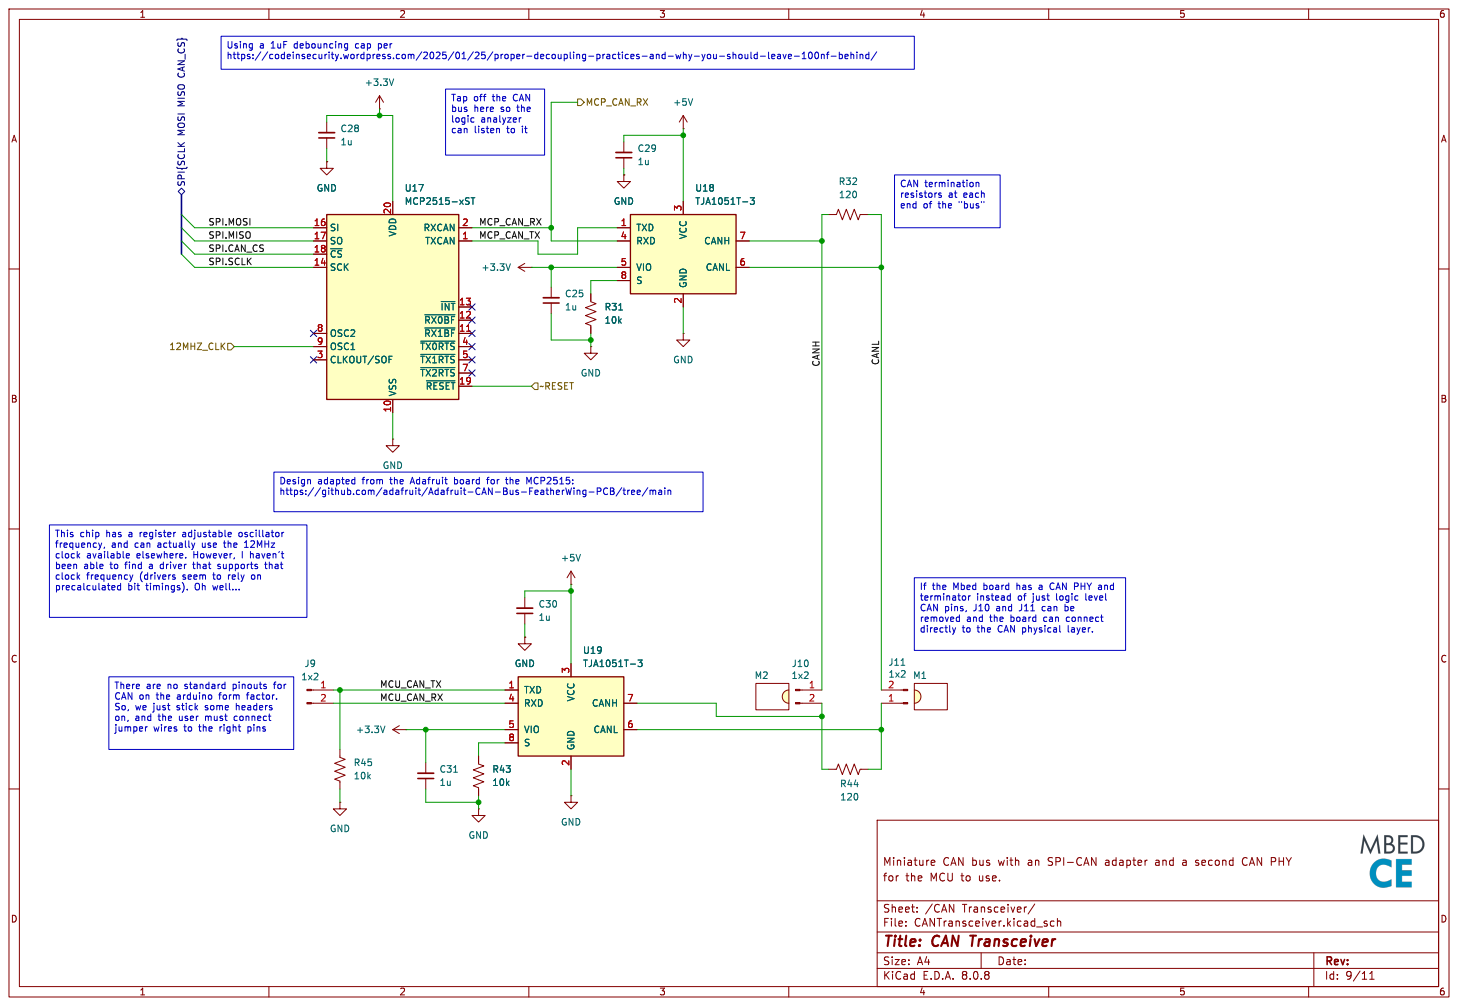
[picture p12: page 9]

Tap off the CAN
bus here so the

end of the "bus" Design adapted from the Adafruit board for the MCP2515: https://github.com/adafruit/Adafruit-CAN-Bus-FeatherWing-PCB/tree/main

3 RXD 4 VIO 5 CANL 6 CANH 7 S

If the Mbed board has a CAN PHY and

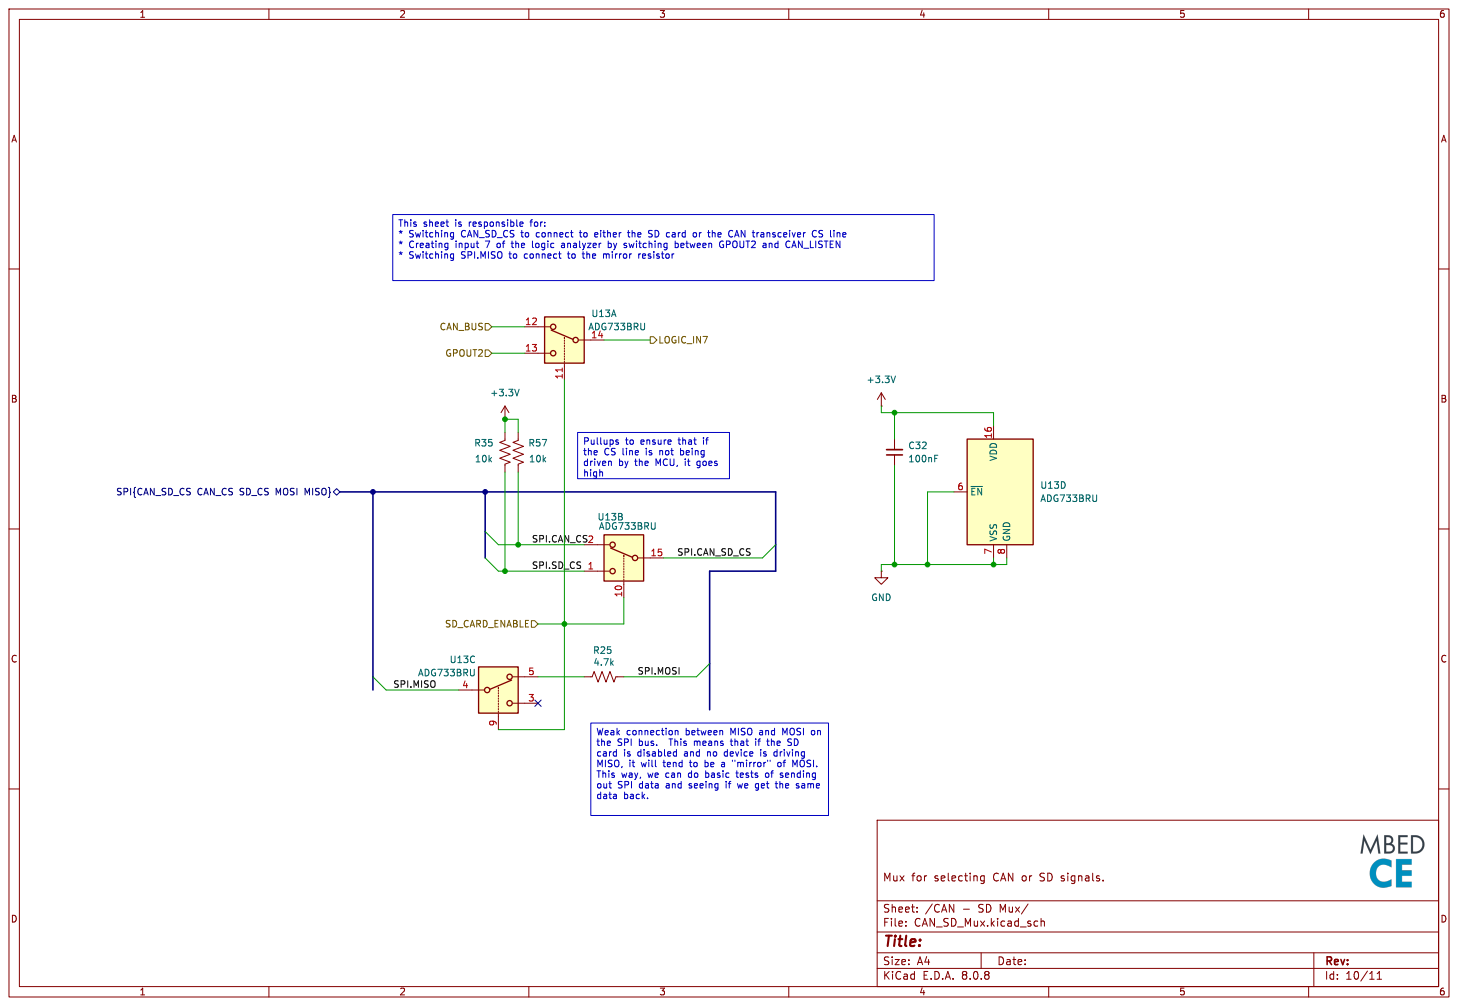
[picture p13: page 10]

SPI.MOSI Pullups to ensure that if
the CS line is not being

out SPI data and seeing if we get the same
data back.

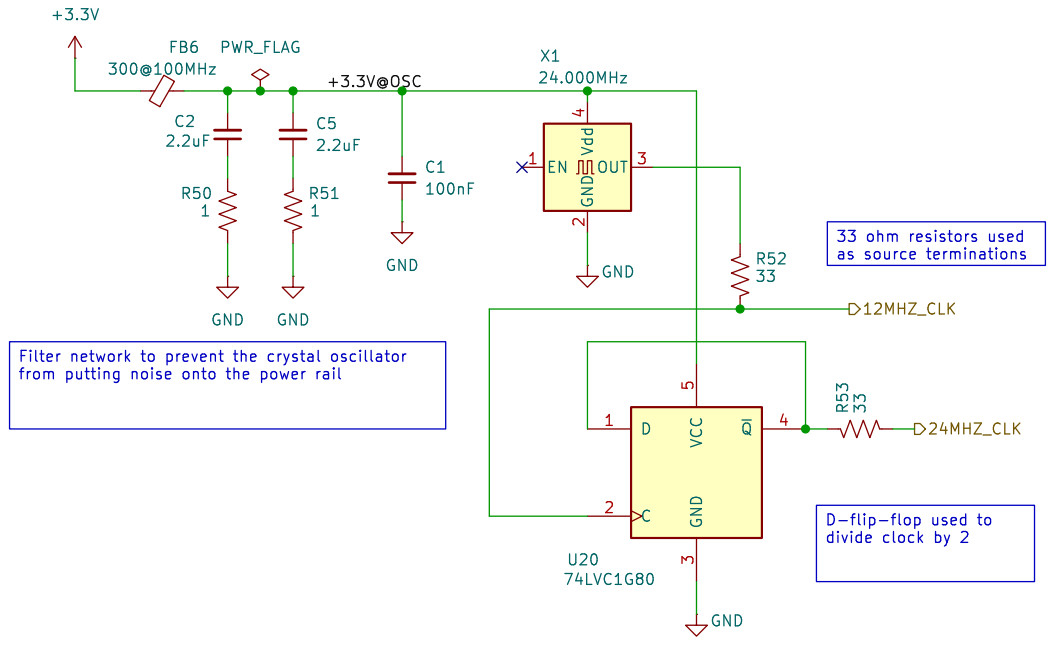
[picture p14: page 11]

as source terminations Filter network to prevent the crystal oscillator

Id: 11/11 Title: File: Oscillators.kicad_sch Sheet: /Oscillators/ GND

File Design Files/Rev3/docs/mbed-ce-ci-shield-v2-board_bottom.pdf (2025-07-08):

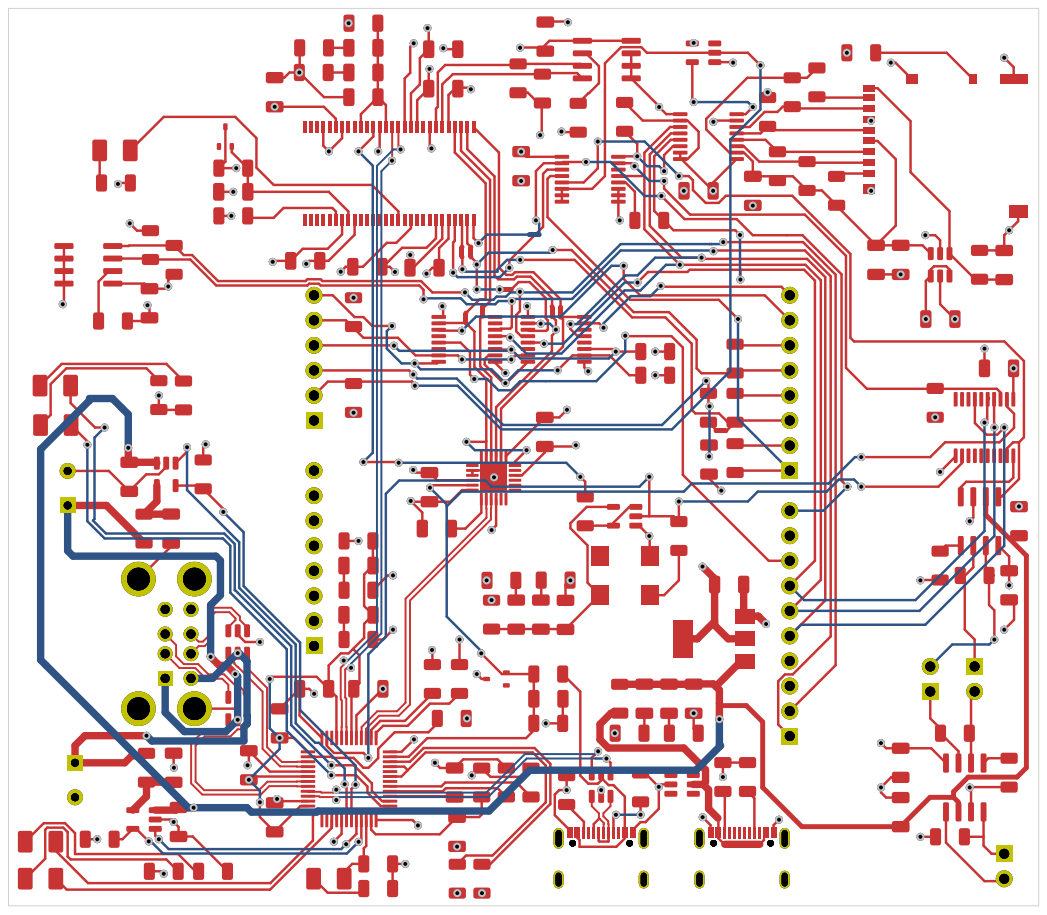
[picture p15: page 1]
Size: A4; Rev: 0; KiCad; E.D.A. 8.0.8+1 + KiBot v1.8.4; Date: 2023-09-05

Sheet: Assembly
File: mbed-ce-ci-shield-v2.kicad_pcb
Title: Mbed CE CI Shield V2

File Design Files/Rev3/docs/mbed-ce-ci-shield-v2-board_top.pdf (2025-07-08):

## V2 Rev 3

## Mbed CE CI Shield


Sheet: Assembly
File: mbed-ce-ci-shield-v2.kicad_pcb
Title: Mbed CE CI Shield V2
KiCad E.D.A. 8.0.8+1 + KiBot v1.8.4

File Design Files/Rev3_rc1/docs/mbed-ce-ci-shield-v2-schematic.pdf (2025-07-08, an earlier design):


regular I2C but should give

I2C{SCL SDA}
UART{MCU_TX MCU_RX RTS}
SPI{SCLK MOSI MISO CAN_SD_CS HW_CS}

SPI{SCLK MOSI MISO HW_CS}

1: UART.MCU_TX/I2C.SDA/SPI.MOSI 2: SPI.MISO

File: mbed-ce-ci-shield-v2.kicad_sch Sheet: /
Id: 1/10 Title: Mbed CE CI Shield v2


- A 100nF for each VCC_A pin, plus 2x 1uF on VCC_A, plus a ferrite bead
- A 100nF for each VCC_D, plus a ferrite bead

Regulator Power Pins VCC_A 1 VCC_A 12 GND 13 VCC_A 16 VCC_A 19 GND 2 GND 20 VCC_D 34 VCC_D 38 VCC 47 VREG 48 VCC_A 7 GND 8 U2A CY7C65632-48AXCT C4

External port power switches

RC timer is used to bring the hub chip's
reset line high ~10ms after VBUS from the

3.3V for use as a general reset signal, and makes sure that the reset isn't high if

Hub Active LED: Lights up when hub is active (NOT in

set that the PWR pins
can act independently.

Id: 2/10 Title: USB Hub


3.3.2), so we ground it to disable the wakeup functionality. Note: SCB_0 and SCB_1 are never needed at

the same time, so to avoid needing a 3rd
requires GPIO_2 and GPIO_6 to be set as

UART{MCU_TX MCU_RX RTS}
I2C{SCL SDA}
SPI{SCLK MOSI MISO HW_CS}


there are 2 AVCC pins and 6 VCC pins, each
FX2_VDDA USB.D- USB.D+

24.000MHz R40
100nF GND
address pins should be set to 001. Reset uses an RC timer with a 10ms time

4 SDA 5 SCL 6 WP 7 VCC

as its status LED. On = ready,


card driver does not work with HW CS anyway
usually only works with a hardware CS pin, HW_CS

time of roughly 10ms. Source: https://www.allaboutcircuits.com/technical-articles/


ADG733BRU SPI{SCLK MOSI MISO CAN_SD_CS} SD_CARD_ENABLE

from SPI we pull its pins down to

pull it high to stop
noise from coupling
on to the bus in this

out SPI data and seeing if we get the same

Id: 6/10 Title: MicroSD Card


4 SDA 5 SCL 6 WP 7 VCC

form factor of EEPROM is sort of a de-facto
standard


diode, then a ferrite bead

before going to the rest of

Id: 8/10 Title: Power Input USB Port File: PowerUSBPort.kicad_sch Sheet: /PowerUSBPort/


Tap off the CAN
bus here so the

3 RXD 4 VIO 5 CANL 6 CANH 7 S

SPI.MOSI SPI.MISO

If the Mbed board has a CAN
PHY, instead of just logic
level CAN pins, J10 and J11
can be removed and the
board can connect directly


* Creating input 7 of the logic

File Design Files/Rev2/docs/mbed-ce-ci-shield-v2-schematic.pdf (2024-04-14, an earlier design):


regular I2C but should give

File: I2CEEPROM.kicad_sch UART{MCU_TX MCU_RX RTS CTS}

UART{MCU_TX MCU_RX RTS CTS}
SPI{SCLK MOSI MISO SD_CS HW_CS}

1: UART.MCU_TX/I2C.SDA/SPI.MOSI 2: UART.RTS/SPI.MISO

Logic Analyzer File: logic_analyzer.kicad_sch PowerUSBPort File: PowerUSBPort.kicad_sch

File: mbed-ce-ci-shield-v2.kicad_sch Sheet: /
Id: 1/8 Title: Mbed CE CI Shield v2


- A 100nF for each VCC_A pin, plus 2x 1uF on VCC_A, plus a ferrite bead

Regulator Power Pins VCC_A 1 VCC_A 12 GND 13 VCC_A 16 VCC_A 19 GND 2 GND 20 VCC_D 34 VCC_D 38 VCC 47 VREG 48 VCC_A 7 GND 8 U2A CY7C65632-48AXCT C2

Hub Active LED: Lights up when hub is active (NOT in

set that the PWR pins
can act independently.

Id: 2/8 Title: USB Hub


the same time, so to avoid needing a 3rd
requires GPIO_2 and GPIO_6 to be set as

SPI{SCLK MOSI MISO SD_CS HW_CS}

Id: 3/8 Title: File: USBSerialAdapter.kicad_sch Sheet: /USBSerialAdapter/


there are 2 AVCC pins and 6 VCC pins, each
FX2_VDDA USB.D- USB.D+

300@100MHz
address pins should be set to 001. Reset uses an RC timer with a 10ms time

as its status LED. On = ready,


can be any GPIO pin since the SD card driver does not work with HW CS anyway

only works with a hardware CS pin, HW_CS should be

time of roughly 10ms. Source: https://www.allaboutcircuits.com/technical-articles/


from SPI we pull its pins down to

File: MicroSDCard.kicad_sch Sheet: /MicroSDCard/ VDD 16

Id: 6/8 Title: MicroSD Card


4 SDA 5 SCL 6 WP 7 VCC

form factor of EEPROM is sort of a de-facto
standard


VBUS is sent through a TVS
diode, then a ferrite bead

before going to the rest of

Id: 8/8 Title: Power Input USB Port File: PowerUSBPort.kicad_sch Sheet: /PowerUSBPort/

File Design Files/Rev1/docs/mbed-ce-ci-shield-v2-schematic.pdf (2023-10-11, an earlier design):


12MHZ_CLK Mbed CE CI Shield V2

regular I2C but should give

File: I2CEEPROM.kicad_sch UART{MCU_TX MCU_RX RTS CTS}

GPOUT[0..2] ArduinoConnector File: ArduinoConnector.kicad_sch

UART{MCU_TX MCU_RX RTS CTS}
SPI{SCLK MOSI MISO SD_CS HW_CS}

SPI{SCLK MOSI MISO SD_CS HW_CS} MicroSDCard File: MicroSDCard.kicad_sch PowerUSBPort File: PowerUSBPort.kicad_sch

1: UART.MCU_TX/I2C.SDA/SPI.MOSI 2: UART.RTS/SPI.MISO

File: mbed-ce-ci-shield-v2.kicad_sch Sheet: /
Id: 1/8 Title: Mbed CE CI Shield v2


- A 100nF for each VCC_A pin, plus 2x 1uF on VCC_A, plus a ferrite bead

set that the PWR pins
can act independently.

Id: 2/8 Title: USB Hub


4 VREGIN 40 AGND 41 TEST 42 EEDATA 43 EECLK 44 EECS 45 VCCIO 46 GND 47 GND 48 REF 5 DM 6 DP 7 VPLL

3 ACBUS6 30 ACBUS7 31 ACBUS8 32 ACBUS9 33 ~{RESET} 34 GND 35 GND 36 VCCA 37 VCCCORE 38 VCCD 39 AGND

I2C{SCL SDA}
SPI{SCLK MOSI MISO SD_CS HW_CS}

support clock
stretching.
Luckily, ADBUS7
is an input in


there are 2 AVCC pins and 6 VCC pins, each
FX2_VDDA USB.D- USB.D+

24.000MHz R40
100nF GND
address pins should be set to 001. Reset uses an RC timer with a 10ms time

4 SDA 5 SCL 6 WP 7 VCC

as its status LED. On = ready,


can be any GPIO pin since the SD card driver does not work with HW CS anyway
I2C.SDA D1/TX
AREF D10/CS D12/MISO
SPI.SCLK UART.MCU_TX UART.MCU_RX
SPI.MOSI SPI.SD_CS
SPI.HW_CS

only works with a hardware CS pin, HW_CS should be

time of roughly 10ms. Source: https://www.allaboutcircuits.com/technical-articles/

Id: 5/8 Title: Arduino Connector File: ArduinoConnector.kicad_sch Sheet: /ArduinoConnector/ C36


labels on the symbol don't match up. +3.3V U14

the MOSI and MISO lines through a tri-state

File: MicroSDCard.kicad_sch Sheet: /MicroSDCard/
Id: 6/8 Title: MicroSD Card


4 SDA 5 SCL 6 WP 7 VCC

form factor of EEPROM is sort of a de-facto
standard


VBUS is sent through a TVS
diode, then a ferrite bead

before going to the rest of

Id: 8/8 Title: Power Input USB Port File: PowerUSBPort.kicad_sch Sheet: /PowerUSBPort/





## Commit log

2023-09-01 Initial commit. Working on USB hub schematic
    [mbed-ce-ci-shield-v2.kicad_pcb, mbed-ce-ci-shield-v2.kicad_sch, usb_hub.kicad_sch]
2023-09-04 More work on USB hub
    [mbed-ce-ci-shield-v2.kicad_sch, usb_hub.kicad_sch]
2023-09-04 Add AA3528 footprint
2023-09-05 Finish USB hub sheet
    [FT232H.kicad_sch, logic_analyzer.kicad_sch, mbed-ce-ci-shield-v2.kicad_pcb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]
2023-09-06 Start on FT232H sheet
    [FT232H.kicad_sch, logic_analyzer.kicad_sch, mbed-ce-ci-shield-v2.kicad_pcb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]
2023-09-10 Add arduino shield schematic, finish FT232H
    [ArduinoConnector.kicad_sch, FT232H.kicad_sch, mbed-ce-ci-shield-v2.kicad_pcb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]
2023-09-11 Finish up initial schematic
    [ArduinoConnector.kicad_sch, FT232H.kicad_sch, I2CEEPROM.kicad_sch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]
2023-09-12 Fix logic analyzer debouncing, progress on routing PCB
    [I2CEEPROM.kicad_sch, logic_analyzer.kicad_sch, mbed-ce-ci-shield-v2.kicad_pcb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]
2023-09-13 Fix some ERC errors
    [logic_analyzer.kicad_sch, usb_hub.kicad_sch]
2023-09-13 Finish routing PCB
    [mbed-ce-ci-shield-v2.kicad_pcb]
2023-09-14 Add logo to PCB, add last labels, fix DRC
    [FT232H.kicad_sch, mbed-ce-ci-shield-v2.kicad_pcb, mbed-ce-ci-shield-v2.kicad_sch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]
2023-09-15 Add license, start adding KiBot files
    [PowerUSBPort.kicad_sch]
2023-09-18 Add part numbers for capacitors, start working on BoM job
    [ArduinoConnector.kicad_sch, FT232H.kicad_sch, I2CEEPROM.kicad_sch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]
2023-09-19 Fill in all part numbers, add pcbinv bom job
    [ArduinoConnector.kicad_sch, FT232H.kicad_sch, I2CEEPROM.kicad_sch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]
2023-09-19 Make sure to install pcbdraw
2023-09-19 looks like there isn't a pcbdraw package :(
2023-09-22 Finish assigning schematic part numbers
    [ArduinoConnector.kicad_sch, logic_analyzer.kicad_sch, mbed-ce-ci-shield-v2.kicad_sch]
2023-10-11 Start documenting project
    [mbed-ce-ci-shield-v2.brd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]
2023-12-03 Add diode on SD card CS line, fix position of PWM/analog testing capacitor
    [ArduinoConnector.kicad_sch, FT232H.kicad_sch, MicroSDCard.kicad_sch]
2023-12-11 Start on SD card and usb-serial changes
    [MicroSDCard.kicad_sch, mbed-ce-ci-shield-v2.kicad_pcb]
2024-01-28 Update MicroSD card socket to have analog switch
    [ArduinoConnector.kicad_sch, MicroSDCard.kicad_sch, mbed-ce-ci-shield-v2.kicad_pcb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]
2024-02-26 Friendship ended with FT232H, now CY7C652xx is my friend
    [ArduinoConnector.kicad_sch, I2CEEPROM.kicad_sch, MicroSDCard.kicad_sch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]
2024-03-10 Finish Rev 2 schematic, start on routing
    [ArduinoConnector.kicad_sch, USBSerialAdapter.kicad_sch, mbed-ce-ci-shield-v2.kicad_pcb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]
2024-04-14 Finish routing v2.r2
    [MicroSDCard.kicad_sch, USBSerialAdapter.kicad_sch, mbed-ce-ci-shield-v2.kicad_pcb]
2024-04-14 Fix some missing suppliers, remove old sheet
    [FT232H.kicad_sch, MicroSDCard.kicad_sch, USBSerialAdapter.kicad_sch]
2024-04-14 Fix some missing silkscreen labels
    [ArduinoConnector.kicad_sch, mbed-ce-ci-shield-v2.kicad_pcb]
2024-04-14 Add Rev2 design files
    [mbed-ce-ci-shield-v2.brd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]
2024-04-14 Update link to schematic
2024-04-28 Update logic analyzer mapping for new board rev
2025-04-01 Update to KiCAD 8, start adding CAN transceiver
    [ArduinoConnector.kicad_sch, I2CEEPROM.kicad_sch, MicroSDCard.kicad_sch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]
2025-04-19 Fix all known issues with v2 r2: * Invert polarity of SD card enable line to match power switch * Decrease SPI mirror resistor resistance * Pull up SD card MISO line to 3V3 * Fix reset voltage divide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
    [ArduinoConnector.kicad_sch, MicroSDCard.kicad_sch, mbed-ce-ci-shield-v2.kicad_pcb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]
2025-04-19 Fix RTS & CTS pin mappings
    [USBSerialAdapter.kicad_sch, mbed-ce-ci-shield-v2.kicad_pcb]
2025-04-19 Start adding CAN support... ~75% done with schematics
    [ArduinoConnector.kicad_sch, CANTransceiver.kicad_sch, CAN_SD_Mux.kicad_sch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]
2025-04-26 ERC passing!
    [ArduinoConnector.kicad_sch, CANTransceiver.kicad_sch, CAN_SD_Mux.kicad_sch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]
2025-04-26 Finish routing
    [mbed-ce-ci-shield-v2.kicad_pcb, usb_hub.kicad_sch]
2025-04-26 Cleanups and more documentation
    [ArduinoConnector.kicad_sch, CANTransceiver.kicad_sch, CAN_SD_Mux.kicad_sch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]
2025-05-22 Kate's suggestions, part 1
    [CANTransceiver.kicad_sch, MicroSDCard.kicad_sch, Oscillators.kicad_sch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]
2025-07-05 Finish new SD card schematic, ERC passing!
    [ArduinoConnector.kicad_sch, CANTransceiver.kicad_sch, CAN_SD_Mux.kicad_sch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]
2025-07-08 Route PCB
    [mbed-ce-ci-shield-v2.kicad_pcb]
2025-07-08 Fix some unrouted nets
    [mbed-ce-ci-shield-v2.kicad_pcb, usb_hub.kicad_sch]
2025-07-08 One more violation
    [mbed-ce-ci-shield-v2.kicad_pcb]
2025-07-08 Add design files
    [mbed-ce-ci-shield-v2.brd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]
2025-07-08 Fix some BOM isues
    [MicroSDCard.kicad_sch, Oscillators.kicad_sch, PowerUSBPort.kicad_sch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]
2025-07-09 Update PCB from schematic
    [mbed-ce-ci-shield-v2.kicad_pcb]
2025-07-09 Oops, fix wrong LibRef for 4.7k resistor
    [CAN_SD_Mux.kicad_sch, mbed-ce-ci-shield-v2.kicad_pcb, usb_hub.kicad_sch]
2025-07-16 Rev 3 release
    [mbed-ce-ci-shield-v2-bom-pcbinv.csv, mbed-ce-ci-shield-v2.brd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]
2025-07-18 Switch out multiplexer, start switch FX2LP out for RP2040
    [ArduinoConnector.kicad_sch, CANTransceiver.kicad_sch, CAN_SD_Mux.kicad_sch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]
2025-08-05 Start on Rev 4, switch to RPi Pico
    [CAN_SD_Mux.kicad_sch, Oscillators.kicad_sch, logic_analyzer.kicad_sch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]
2025-08-05 Fix some issues with rev 3 built PCB
    [CANTransceiver.kicad_sch, mbed-ce-ci-shield-v2.kicad_pcb]
2025-11-30 Add blank space for serial number
    [mbed-ce-ci-shield-v2.kicad_pcb]
2026-03-25 Update config to be correct for 3.3V self powered operation
2026-09-13 Update to KiCAD 10, start integrating RP2350
    [ArduinoConnector.kicad_sch, CANTransceiver.kicad_sch, CAN_SD_Mux.kicad_sch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]
2026-09-14 Route RP2 switching voltage reg
    [logic_analyzer.kicad_sch, mbed-ce-ci-shield-v2.kicad_pcb, mbed-ce-ci-shield-v2.kicad_sch]
2026-09-15 Keep working on routing
    [logic_analyzer.kicad_sch]
2026-10-07 Finish schematic and placement for all remaining RP2354 power passives
2026-10-16 Add power flag
2026-10-16 Fix some minor BOM issues
